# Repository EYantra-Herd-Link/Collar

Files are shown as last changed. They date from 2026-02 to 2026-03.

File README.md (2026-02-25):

# HerdLink Collar V1

HerdLink Collar V1 is a smart edge-computing tracking and health monitoring collar designed for livestock. Built around the Seeed Studio XIAO ESP32-C3, the collar integrates motion sensing, temperature and humidity monitoring, and audio analysis to infer animal behaviors such as grazing, ruminating, walking, and resting. It transmits telemetry data wirelessly via UDP.

## Features

*   **Behavioral Inference:** Utilizes a 6-axis IMU (MPU6050) to calculate activity jerk and variance, categorizing behavior into states like Grazing, Ruminating, Walking, Resting, and High/Low Activity Alerts.
*   **Audio Edge Processing:** Captures audio via an I2S microphone and performs on-device Fast Fourier Transform (FFT) to extract Mel-frequency features and audio magnitude.
*   **Health & Environmental Monitoring:** Measures body temperature using a Dallas DS18B20 sensor and environmental temperature/humidity using an AHT20 sensor.
*   **Power Efficiency:** Implements FreeRTOS tasks, hardware interrupts, and sleep modes (ESP32 Light Sleep) to optimize battery life.
*   **Wireless Telemetry:** Broadcasts structured JSON telemetry payloads over WiFi via UDP for local network collection.

## Hardware Components

*   **Microcontroller:** Seeed Studio XIAO ESP32-C3
*   **Motion Sensor:** MPU6050 (Accelerometer & Gyroscope)
*   **Body Temperature Sensor:** Dallas DS18B20 (OneWire)
*   **Environment Sensor:** AHT20 (Temperature & Humidity)
*   **Microphone:** I2S Microphone
*   **Custom PCB:** KiCad designs included for the main logic board and power management board.

## Project Structure

*   `Board Firmware/Sender/`: C++ PlatformIO project containing the ESP32-C3 edge firmware.
*   `Board Firmware/Reciever/`: Python script to receive and decode UDP telemetry data.
*   `PCB_Design/HerdLinkV1/`: KiCad project and Gerber files for the main collar PCB.
*   `PCB_Design/HerdLinkV1 Power/PowerBoard/`: KiCad project for the power management board.

## Setup and Installation

### 1. Firmware (Sender)

The firmware is built using PlatformIO.

1.  Open the `Board Firmware/Sender` directory in VS Code with the PlatformIO extension installed.
2.  Before flashing, update the WiFi credentials in `src/main.cpp`:
    ```cpp
    const char* WIFI_SSID     = "Your_SSID";
    const char* WIFI_PASSWORD = "Your_PASSWORD";
    ```
3.  Connect the XIAO ESP32-C3 and click the PlatformIO "Upload" button to compile and flash the firmware.

### 2. Receiver (Python script)

The receiver is a lightweight Python script that listens for incoming UDP packets.

1.  Navigate to the receiver directory:
    ```bash
    cd "Board Firmware/Reciever"
    ```
2.  Run the script (requires Python 3):
    ```bash
    python CowPilled.py
    ```
    The script will bind to `0.0.0.0:4210` and print incoming JSON telemetry payloads to the console.

## Telemetry Data Format

The device transmits data in JSON format over UDP. Example payload structure:

```json
{
  "id": "MAC_ADDRESS",
  "seq": 123,
  "ts": 1645000,
  "bt": 38.5,
  "et": 24.2,
  "eh": 45.0,
  "ax": 0.05,
  "ay": 0.98,
  "az": 0.12,
  "gx": 1.50,
  "gy": -0.20,
  "gz": 0.10,
  "gy_var": 0.054,
  "jerk": 45.2,
  "mot_int": 0,
  "err": 0,
  "v": 0.00,
  "s": -65,
  "af": [12.4, 45.2, 5.1, 0.0, 0.0, 0.0, 0.0, 0.0]
}
```

*   `id`: Device MAC address
*   `seq`: Sequence number
*   `ts`: Device uptime timestamp (ms)
*   `bt`: Body temperature (Celsius)
*   `et`: Environmental temperature (Celsius)
*   `eh`: Environmental humidity (%)
*   `ax`, `ay`, `az`: Accelerometer data
*   `gx`, `gy`, `gz`: Gyroscope data
*   `gy_var`: Gyroscope Y-axis variance
*   `jerk`: Calculated activity jerk
*   `mot_int`: Motion interrupt flag (1 if triggered, 0 otherwise)
*   `err`: Error code (currently 0)
*   `v`: Voltage (placeholder)
*   `s`: WiFi RSSI signal strength
*   `af`: Array of Audio Features (Mel bins)

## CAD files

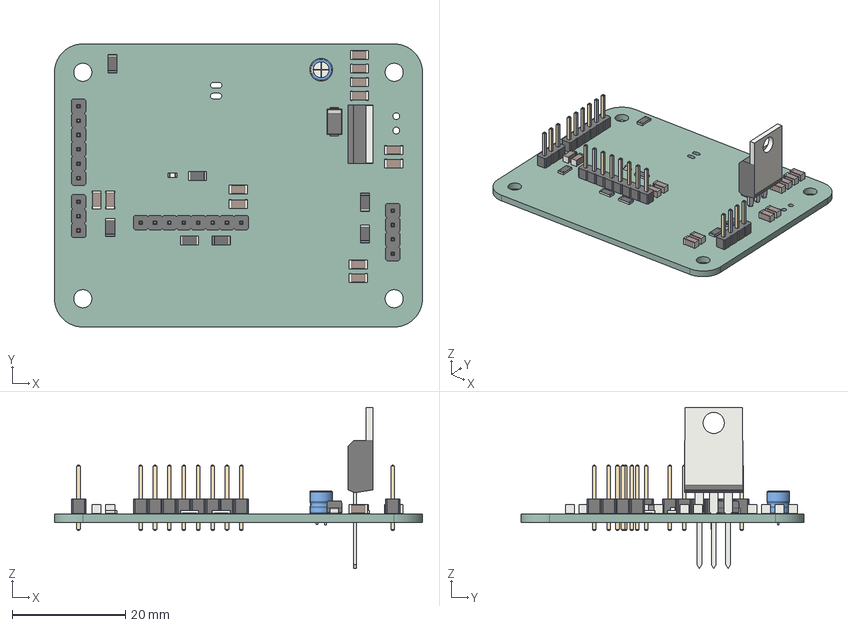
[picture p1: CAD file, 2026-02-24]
HerdLinkV1.step
65.0 x 50.0 x 28.5 mm
C_1206_3216Metric x 12
R_1206_3216Metric x 7
CP_Radial_D4.0mm_P1.50mm
D_SMA
PinHeader_1x03_P2.54mm_Vertical
PinHeader_1x04_P2.54mm_Vertical
PinHeader_1x08_P2.54mm_Vertical
PinHeader_1x06_P2.54mm_Vertical
LED_0603_1608Metric
TO-220-3_Vertical
HerdLinkV1_PCB

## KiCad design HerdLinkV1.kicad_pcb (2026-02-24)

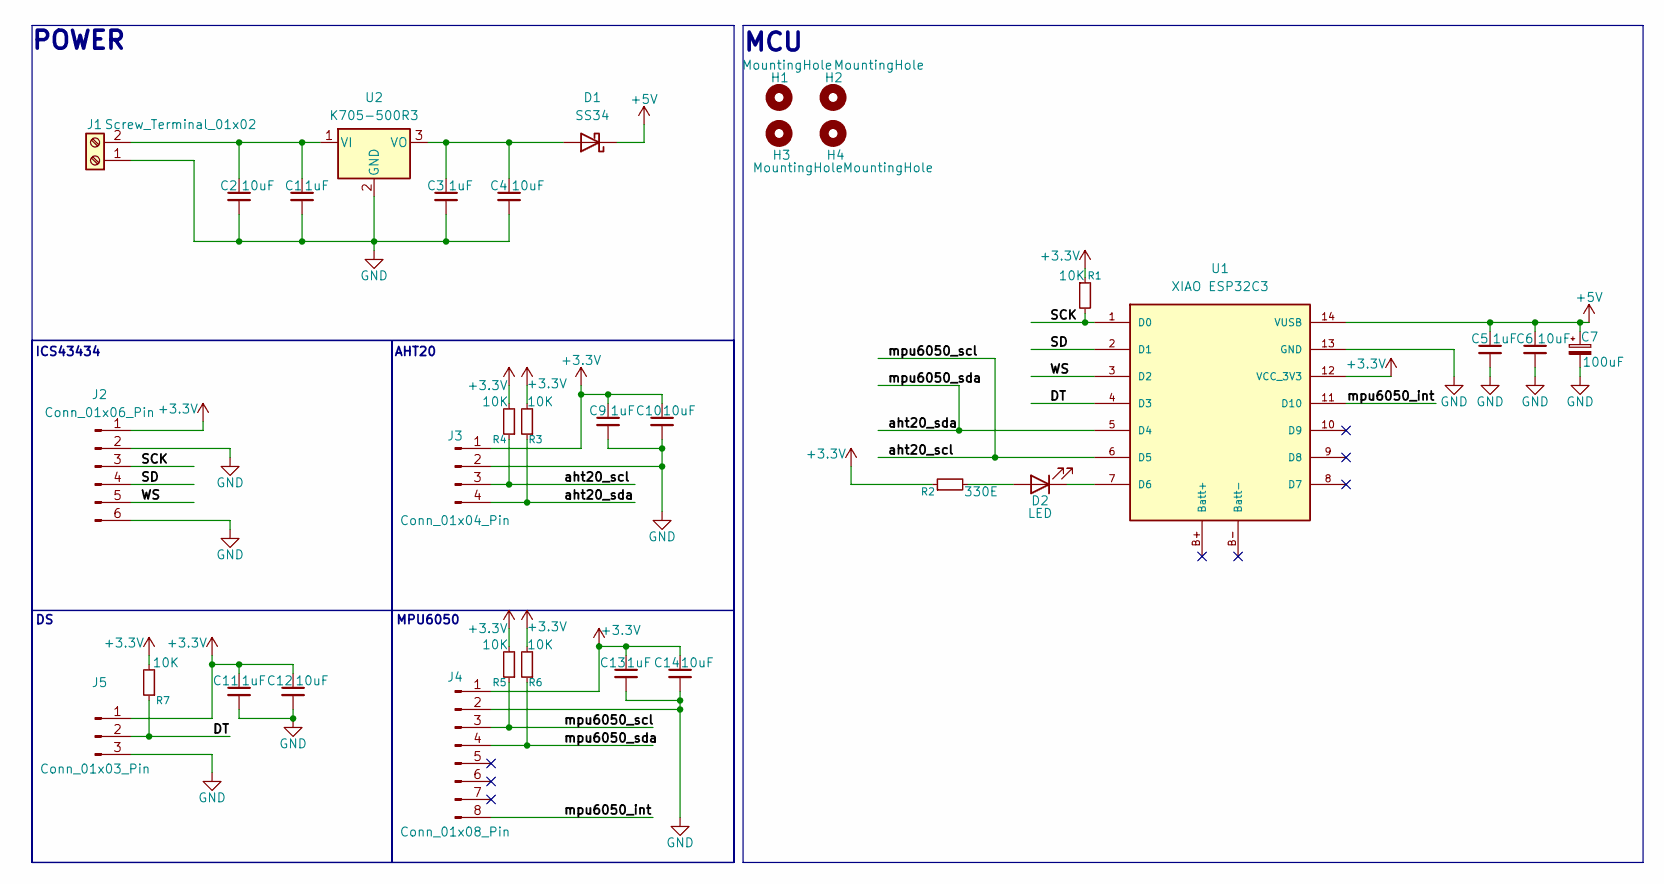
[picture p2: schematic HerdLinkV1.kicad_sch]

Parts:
C1, C3, C5, C9, C11, C13: 1uF; C_1206_3216Metric
C2, C4, C6, C10, C12, C14: 10uF; C_1206_3216Metric
C7: 100uF; CP_Radial_D4.0mm_P1.50mm
D1: SS34; D_SMA
D2: LED; LED_0603_1608Metric
H1, H2, H3, H4: MountingHole; MountingHole_3.2mm_M3
J1: Screw_Terminal_01x02; TerminalBlock_Xinya_XY308-2.54-2P_1x02_P2.54mm_Horizontal
J2: Conn_01x06_Pin; PinHeader_1x06_P2.54mm_Vertical
J3: Conn_01x04_Pin; PinHeader_1x04_P2.54mm_Vertical
J4: Conn_01x08_Pin; PinHeader_1x08_P2.54mm_Vertical
J5: Conn_01x03_Pin; PinHeader_1x03_P2.54mm_Vertical
R1, R3, R4, R5, R6, R7: 10K; R_1206_3216Metric_Pad1.30x1.75mm_HandSolder
R2: 330E; R_1206_3216Metric_Pad1.30x1.75mm_HandSolder
U1: XIAO ESP32C3; xiao_esp32c3
U2: K705-500R3; TO-220-3_Vertical

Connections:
+3.3V: C9.1, C10.1, C11.1, C12.1, C13.1, C14.1, J2.1, J3.1, J4.1, J5.1, R1.1, R2.1, R3.2, R4.2, R5.2, R6.2, R7.2, U1.12 (VCC_3V3)
+5V: C5.1, C6.1, C7.1, D1.1 (K), U1.14 (VUSB)
/DT: J5.2, R7.1, U1.4 (D3)
/SCK: J2.3, R1.2, U1.1 (D0)
/SD: J2.4, U1.2 (D1)
/WS: J2.5, U1.3 (D2)
/aht20_scl: J3.3, J4.3, R4.1, R5.1, U1.6 (D5)
/aht20_sda: J3.4, J4.4, R3.1, R6.1, U1.5 (D4)
/mpu6050_int: J4.8, U1.11 (D10)
GND: C1.2, C2.2, C3.2, C4.2, C5.2, C6.2, C7.2, C9.2, C10.2, C11.2, C12.2, C13.2, C14.2, J1.1, J2.2, J2.6, J3.2, J4.2, J5.3, U1.13 (GND), U2.2 (GND)
unnamed: C3.1, C4.1, D1.2 (A), U2.3 (VO)
unnamed: D2.2 (A), R2.2
unnamed: D2.1 (K), U1.7 (D6)
unnamed: C1.1, C2.1, J1.2, U2.1 (VI)

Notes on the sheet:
MCU
MPU6050
AHT20
ICS43434
POWER

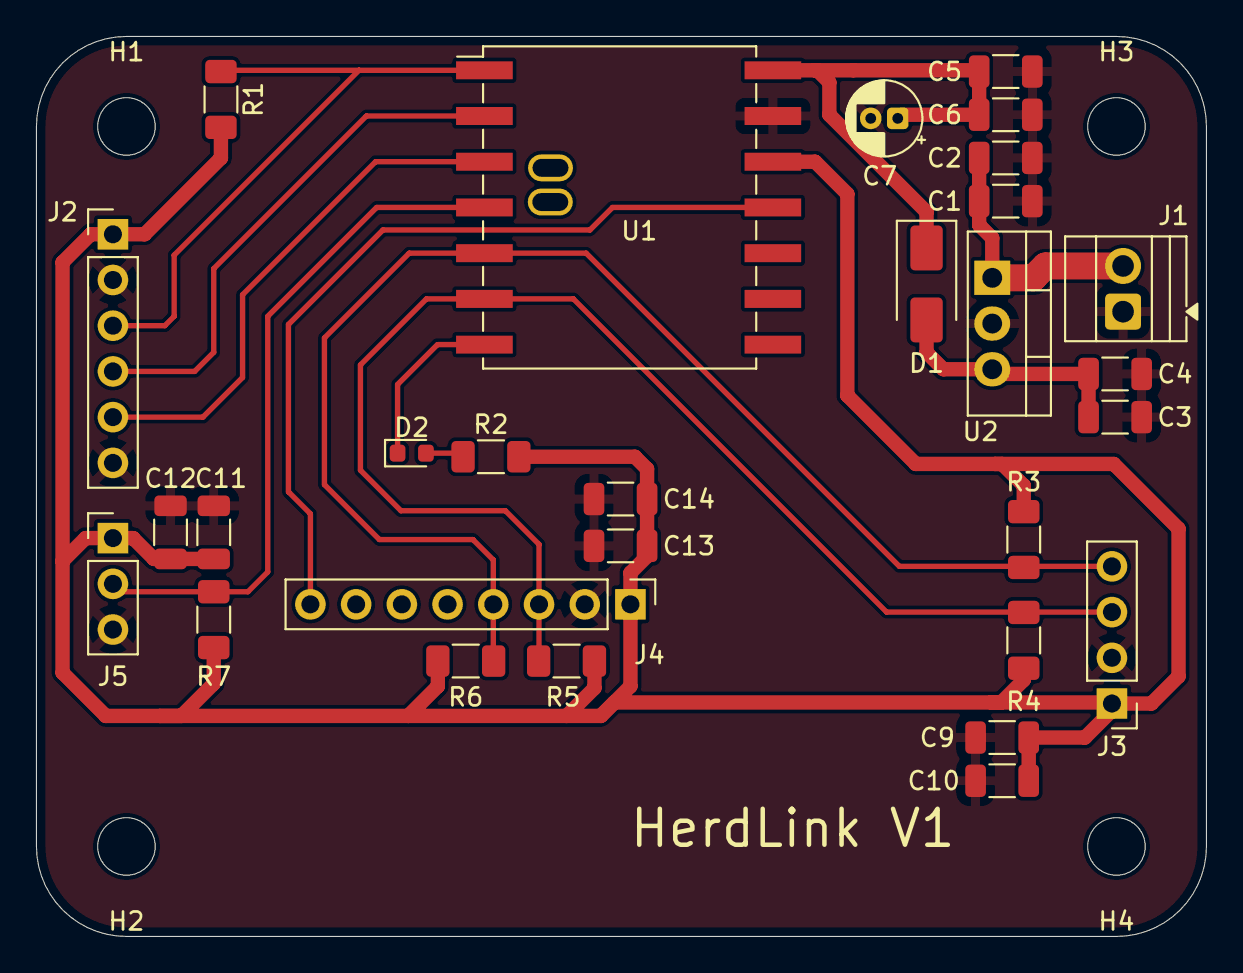
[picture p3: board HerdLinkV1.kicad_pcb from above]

Board: 2 copper layers, 65.0 x 50.0 mm, 33 parts (0 on the bottom side), 14 nets.

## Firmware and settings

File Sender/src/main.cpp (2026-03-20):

#include <Arduino.h>
#include <Wire.h>
#include <Adafruit_MPU6050.h>
#include <Adafruit_Sensor.h>
#include <esp_pm.h>
#include <esp_sleep.h>
#include <WiFi.h>
#include <WiFiUdp.h>
#include <esp_task_wdt.h>
#include <OneWire.h>
#include <DallasTemperature.h>
#include <Adafruit_AHTX0.h>
#include <driver/i2s.h>
#include <esp_mac.h>

#define PIN_I2C_SDA D4
#define PIN_I2C_SCL D5
#define PIN_LED     D6
#define PIN_MPU_INT D10
#define PIN_ONE_WIRE D3

#define I2S_SCK          D0
#define I2S_SD           D1
#define I2S_WS           D2
#define I2S_PORT         I2S_NUM_0
#define AUDIO_SAMPLE_RATE 16000
#define FFT_SIZE          256
#define NUM_MEL_BINS      8

#define IMU_SAMPLES_PER_CYCLE  10
#define IMU_SAMPLE_INTERVAL_MS 100

#define JERK_WALKING  5.0f
#define JERK_GRAZING  1.5f
#define JERK_MIN      0.3f

#define RUMINATION_AUDIO_THRESHOLD 50000.0f

const char* WIFI_SSID     = "placeholder";
const char* WIFI_PASSWORD = "placeholder";
const int   UDP_PORT      = 4210;
const char* TARGET_IP     = "255.255.255.255";

#define SENSOR_POLL_RATE_MS   10000
#define WDT_TIMEOUT_SECONDS   30
#define DS18B20_RESOLUTION    9

Adafruit_MPU6050  mpu;
Adafruit_AHTX0    aht20;
OneWire           oneWire(PIN_ONE_WIRE);
DallasTemperature ds18b20(&oneWire);

TaskHandle_t  TaskSensorHandle;
TaskHandle_t  TaskTelemetryHandle;
TaskHandle_t  TaskAudioHandle;
QueueHandle_t healthDataQueue;
SemaphoreHandle_t audioMutex;
WiFiUDP udp;

uint32_t seqNum    = 0;
bool ds18b20_ok    = false;
bool aht20_ok      = false;
bool mic_ok        = false;
char device_id[18];

float latestAudioMagnitude            = 0.0f;
float latestAudioFeatures[NUM_MEL_BINS] = {0};

int16_t cos_lut[FFT_SIZE / 2];
int16_t sin_lut[FFT_SIZE / 2];
int16_t window_lut[FFT_SIZE];

enum BehaviorState {
  RUMINATING,
  GRAZING,
  RESTING,
  WALKING,
  ALERT_HIGH_ACTIVITY,
  ALERT_LOW_ACTIVITY,
  UNKNOWN_STATE
};

struct HealthRecord {
  uint32_t      seq;
  uint32_t      timestamp;
  float         ax, ay, az;
  float         gx, gy, gz;
  float         gy_variance;
  float         activityJerk;
  bool          is_interrupt;
  float         bodyTemp;
  float         envTemp;
  float         envHum;
  BehaviorState state;
  float         audioMagnitude;
  float         audioFeatures[NUM_MEL_BINS];
};

void initDSP() {
  for (int i = 0; i < FFT_SIZE / 2; i++) {
    cos_lut[i] = (int16_t)(cos(2.0 * PI * i / FFT_SIZE) * 32767.0);
    sin_lut[i] = (int16_t)(sin(2.0 * PI * i / FFT_SIZE) * 32767.0);
  }
  for (int i = 0; i < FFT_SIZE; i++) {
    window_lut[i] = (int16_t)((0.54 - 0.46 * cos(2.0 * PI * i / (FFT_SIZE - 1))) * 32767.0);
  }
}

void int_fft(int16_t *fr, int16_t *fi, int n) {
  int m = 0;
  while ((1 << m) < n) m++;
  int j = 0;
  for (int i = 0; i < n - 1; i++) {
    if (i < j) {
      int16_t tr = fr[j]; int16_t ti = fi[j];
      fr[j] = fr[i]; fi[j] = fi[i];
      fr[i] = tr;    fi[i] = ti;
    }
    int k = n >> 1;
    while (k <= j) { j -= k; k >>= 1; }
    j += k;
  }
  for (int l = 1; l <= m; l++) {
    int le  = 1 << l;
    int le2 = le >> 1;
    for (j = 0; j < le2; j++) {
      int     idx = j << (m - l);
      int16_t wr  = cos_lut[idx];
      int16_t wi  = -sin_lut[idx];
      for (int i = j; i < n; i += le) {
        int     ip = i + le2;
        int32_t tr = ((int32_t)fr[ip] * wr - (int32_t)fi[ip] * wi) >> 15;
        int32_t ti = ((int32_t)fr[ip] * wi + (int32_t)fi[ip] * wr) >> 15;
        fr[ip] = fr[i] - tr;
        fi[ip] = fi[i] - ti;
        fr[i] += tr;
        fi[i] += ti;
      }
    }
  }
}

uint32_t int_sqrt(uint32_t n) {
  uint32_t root = 0;
  uint32_t bit  = 1UL << 30;
  while (bit > n) bit >>= 2;
  while (bit != 0) {
    if (n >= root + bit) {
      n   -= root + bit;
      root = (root >> 1) + bit;
    } else {
      root >>= 1;
    }
    bit >>= 2;
  }
  return root;
}

void IRAM_ATTR mpuInterruptHandler() {
  BaseType_t xHigherPriorityTaskWoken = pdFALSE;
  vTaskNotifyGiveFromISR(TaskSensorHandle, &xHigherPriorityTaskWoken);
  if (xHigherPriorityTaskWoken == pdTRUE) {
    portYIELD_FROM_ISR();
  }
}

void indicateBehavior(BehaviorState state) {
  switch (state) {
    case RUMINATING:
      digitalWrite(PIN_LED, LOW); vTaskDelay(pdMS_TO_TICKS(100));
      digitalWrite(PIN_LED, HIGH); vTaskDelay(pdMS_TO_TICKS(100));
      digitalWrite(PIN_LED, LOW); vTaskDelay(pdMS_TO_TICKS(100));
      digitalWrite(PIN_LED, HIGH);
      break;
    case GRAZING:
      digitalWrite(PIN_LED, LOW); vTaskDelay(pdMS_TO_TICKS(200));
      digitalWrite(PIN_LED, HIGH);
      break;
    case ALERT_HIGH_ACTIVITY:
    case ALERT_LOW_ACTIVITY:
      for (int i = 0; i < 5; i++) {
        digitalWrite(PIN_LED, LOW); vTaskDelay(pdMS_TO_TICKS(50));
        digitalWrite(PIN_LED, HIGH); vTaskDelay(pdMS_TO_TICKS(50));
      }
      break;
    default:
      digitalWrite(PIN_LED, LOW); vTaskDelay(pdMS_TO_TICKS(50));
      digitalWrite(PIN_LED, HIGH);
      break;
  }
}

void audioTask(void *pvParameters) {
  static int32_t raw_buffer[FFT_SIZE];  
  static int16_t fr[FFT_SIZE];
  static int16_t fi[FFT_SIZE];

  esp_task_wdt_add(NULL);

  for (;;) {
    esp_task_wdt_reset();

    if (ulTaskNotifyTake(pdTRUE, pdMS_TO_TICKS(5000)) == 0) {
      continue;
    }

    if (!mic_ok) continue;

    i2s_start(I2S_PORT);

    size_t bytes_read = 0;
    i2s_read(I2S_PORT, raw_buffer, sizeof(raw_buffer), &bytes_read, pdMS_TO_TICKS(100));

    uint64_t total_rms_sum               = 0;
    uint32_t mel_accumulators[NUM_MEL_BINS] = {0};
    int      frames_processed            = 0;
    bool     read_error                  = false;

    for (int i = 0; i < 187; i++) {
      if (i % 10 == 0) esp_task_wdt_reset();

      esp_err_t res = i2s_read(I2S_PORT, raw_buffer, sizeof(raw_buffer),
                               &bytes_read, pdMS_TO_TICKS(200));
      if (res != ESP_OK) {
        read_error = true;
        mic_ok     = false;
        break;
      }

      memset(fi, 0, sizeof(fi));

      for (int j = 0; j < FFT_SIZE; j++) {
        int32_t sample = raw_buffer[j] >> 12;
        fr[j] = (int16_t)((sample * window_lut[j]) >> 15);
        total_rms_sum += (uint64_t)(sample * sample);
      }

      int_fft(fr, fi, FFT_SIZE);

      int bin_width = (FFT_SIZE / 2) / NUM_MEL_BINS;
      for (int k = 0; k < FFT_SIZE / 2; k++) {
        uint32_t mag_sq  = ((uint32_t)(fr[k] * fr[k])) + ((uint32_t)(fi[k] * fi[k]));
        uint32_t mag     = int_sqrt(mag_sq);
        int      mel_idx = k / bin_width;
        if (mel_idx >= NUM_MEL_BINS) mel_idx = NUM_MEL_BINS - 1;
        mel_accumulators[mel_idx] += mag;
      }

      frames_processed++;
      vTaskDelay(pdMS_TO_TICKS(10));
    }

    i2s_stop(I2S_PORT);

    if (!read_error && frames_processed > 0) {
      uint32_t final_rms = int_sqrt(
        (uint32_t)(total_rms_sum / ((uint64_t)frames_processed * FFT_SIZE))
      );

      xSemaphoreTake(audioMutex, portMAX_DELAY);
      latestAudioMagnitude = (float)final_rms;
      for (int i = 0; i < NUM_MEL_BINS; i++) {
        latestAudioFeatures[i] = (float)mel_accumulators[i] / frames_processed;
      }
      xSemaphoreGive(audioMutex);
    }
  }
}

void sensorTask(void *pvParameters) {
  for (;;) {
    bool urgentMotion = false;

    if (ulTaskNotifyTake(pdTRUE, pdMS_TO_TICKS(SENSOR_POLL_RATE_MS)) > 0) {
      urgentMotion = true;
      Serial.println("WAKEUP: Interrupt Fired");
    } else {
      Serial.println("WAKEUP: Timer Poll");
    }

    digitalWrite(PIN_LED, LOW);

    float bTemp = 0.0f, eTemp = 0.0f, eHum = 0.0f;

    if (ds18b20_ok) {
      bTemp = ds18b20.getTempCByIndex(0);
      ds18b20.requestTemperatures();
      if (bTemp == DEVICE_DISCONNECTED_C || bTemp < -50.0f) {
        bTemp       = 0.0f;
        ds18b20_ok  = false;
      }
    } else {
      if (ds18b20.getDeviceCount() > 0) {
        ds18b20.setResolution(DS18B20_RESOLUTION);
        ds18b20.requestTemperatures();
        ds18b20_ok = true;
      }
    }

    if (aht20_ok) {
      sensors_event_t humidity, temp;
      if (aht20.getEvent(&humidity, &temp)) {
        eTemp = temp.temperature;
        eHum  = humidity.relative_humidity;
      } else {
        aht20_ok = false;
      }
    } else {
      if (aht20.begin()) {
        aht20_ok = true;
      }
    }

    mpu.enableCycle(false);
    mpu.enableSleep(false);
    vTaskDelay(pdMS_TO_TICKS(10));

    float sumAx = 0, sumAy = 0, sumAz = 0;
    float sumGx = 0, sumGy = 0, sumGz = 0;
    float gyroYSamples[IMU_SAMPLES_PER_CYCLE];
    float totalJerk  = 0.0f;
    float prevMag    = 0.0f;
    int   validSamples = 0;

    for (int i = 0; i < IMU_SAMPLES_PER_CYCLE; i++) {
      sensors_event_t a, g, temp;
      if (mpu.getEvent(&a, &g, &temp)) {
        sumAx += a.acceleration.x;
        sumAy += a.acceleration.y;
        sumAz += a.acceleration.z;
        sumGx += g.gyro.x;
        sumGy += g.gyro.y;
        sumGz += g.gyro.z;
        gyroYSamples[validSamples] = g.gyro.y;

        float mag = sqrt(a.acceleration.x * a.acceleration.x +
                         a.acceleration.y * a.acceleration.y +
                         a.acceleration.z * a.acceleration.z);
        if (i > 0) totalJerk += abs(mag - prevMag);
        prevMag = mag;
        validSamples++;
      }
      vTaskDelay(pdMS_TO_TICKS(IMU_SAMPLE_INTERVAL_MS));
    }

    HealthRecord rec = {0};
    rec.seq          = seqNum++;
    rec.timestamp    = millis();
    rec.is_interrupt = urgentMotion;
    rec.bodyTemp     = bTemp;
    rec.envTemp      = eTemp;
    rec.envHum       = eHum;

    if (validSamples > 0) {
      rec.ax = sumAx / validSamples;
      rec.ay = sumAy / validSamples;
      rec.az = sumAz / validSamples;
      rec.gx = sumGx / validSamples;
      rec.gy = sumGy / validSamples;
      rec.gz = sumGz / validSamples;

      float mean     = rec.gy;
      float variance = 0.0f;
      for (int i = 0; i < validSamples; i++) {
        float diff = gyroYSamples[i] - mean;
        variance += diff * diff;
      }
      rec.gy_variance = variance / validSamples;
    }

    rec.activityJerk = (validSamples > 1) ? totalJerk / (validSamples - 1) : 0.0f;

    if (urgentMotion) {
      rec.state = ALERT_HIGH_ACTIVITY;
      if (mic_ok) {
        xTaskNotifyGive(TaskAudioHandle);
      }
    } else if (rec.activityJerk > JERK_WALKING * 2.0f) {
      rec.state = ALERT_HIGH_ACTIVITY;
    } else if (rec.activityJerk > JERK_WALKING) {
      rec.state = WALKING;
    } else if (rec.activityJerk > JERK_GRAZING) {
      rec.state = GRAZING;
    } else {
      rec.state = RESTING;
    }

    indicateBehavior(rec.state);

    xSemaphoreTake(audioMutex, portMAX_DELAY);
    rec.audioMagnitude = latestAudioMagnitude;
    for (int i = 0; i < NUM_MEL_BINS; i++) {
      rec.audioFeatures[i] = latestAudioFeatures[i];
    }
    latestAudioMagnitude = 0.0f;
    memset(latestAudioFeatures, 0, sizeof(latestAudioFeatures));
    xSemaphoreGive(audioMutex);

    if (rec.state == RESTING && rec.audioMagnitude > RUMINATION_AUDIO_THRESHOLD) {
      rec.state = RUMINATING;
    }

    xQueueSend(healthDataQueue, &rec, pdMS_TO_TICKS(100));

    mpu.setInterruptPinLatch(false);
    mpu.setCycleRate(MPU6050_CYCLE_40_HZ);
    mpu.enableCycle(true);

    vTaskDelay(pdMS_TO_TICKS(100));
    digitalWrite(PIN_LED, HIGH);

    if (urgentMotion) {
      mpu.getMotionInterruptStatus();
    }
  }
}

void telemetryTask(void *pvParameters) {
  esp_task_wdt_add(NULL);

  for (;;) {
    esp_task_wdt_reset();

    HealthRecord rec;
    if (xQueueReceive(healthDataQueue, &rec, pdMS_TO_TICKS(5000)) == pdPASS) {

      if (WiFi.status() != WL_CONNECTED) {
        Serial.println("WiFi: Connecting...");
        WiFi.begin(WIFI_SSID, WIFI_PASSWORD);
        int retries = 0;
        while (WiFi.status() != WL_CONNECTED && retries < 10) {
          esp_task_wdt_reset();
          vTaskDelay(pdMS_TO_TICKS(500));
          retries++;
        }
        if (WiFi.status() == WL_CONNECTED) {
          Serial.println("WiFi: Connected!");
        } else {
          Serial.println("WiFi: Failed to connect.");
        }
      }

      if (WiFi.status() == WL_CONNECTED) {
        char af_buf[128] = "[";
        for (int i = 0; i < NUM_MEL_BINS; i++) {
          char temp[16];
          snprintf(temp, sizeof(temp), "%.2f%s",
                   rec.audioFeatures[i],
                   (i == NUM_MEL_BINS - 1) ? "" : ",");
          strlcat(af_buf, temp, sizeof(af_buf));
        }
        strlcat(af_buf, "]", sizeof(af_buf));

        char payload[896];
        snprintf(payload, sizeof(payload),
          "{"
          "\"id\":\"%s\","
          "\"seq\":%u,"
          "\"ts\":%u,"
          "\"bt\":%.1f,"
          "\"et\":%.1f,"
          "\"eh\":%.1f,"
          "\"ax\":%.2f,\"ay\":%.2f,\"az\":%.2f,"
          "\"gx\":%.2f,\"gy\":%.2f,\"gz\":%.2f,"
          "\"gy_var\":%.3f,"
          "\"jerk\":%.2f,"
          "\"aud\":%.2f,"
          "\"state\":%d,"
          "\"mot_int\":%d,"
          "\"low_act\":%d,"
          "\"err\":0,"
          "\"v\":0.00,"
          "\"s\":%d,"
          "\"af\":%s"
          "}",
          device_id, rec.seq, rec.timestamp,
          rec.bodyTemp, rec.envTemp, rec.envHum,
          rec.ax, rec.ay, rec.az,
          rec.gx, rec.gy, rec.gz,
          rec.gy_variance, rec.activityJerk, rec.audioMagnitude,
          (int)rec.state,
          rec.is_interrupt ? 1 : 0,
          (rec.activityJerk < JERK_MIN && rec.activityJerk >= 0.0f) ? 1 : 0,
          (int)WiFi.RSSI(),
          af_buf
        );

        Serial.println(payload);

        udp.beginPacket(TARGET_IP, UDP_PORT);
        udp.print(payload);
        udp.endPacket();

        Serial.println("UDP: Sent.");
      }

      if (uxQueueMessagesWaiting(healthDataQueue) == 0) {
        WiFi.disconnect(true);
        WiFi.mode(WIFI_OFF);
      }
    }
  }
}

void setup() {
  Serial.begin(115200);
  pinMode(PIN_LED, OUTPUT);
  digitalWrite(PIN_LED, HIGH);

  Wire.begin(PIN_I2C_SDA, PIN_I2C_SCL);
  Wire.setClock(100000);
  Wire.setTimeOut(50);

  esp_pm_config_esp32c3_t pm_config = {
    .max_freq_mhz       = 160,
    .min_freq_mhz       = 10,
    .light_sleep_enable = true
  };
  esp_pm_configure(&pm_config);

  esp_task_wdt_init(WDT_TIMEOUT_SECONDS, true);

  WiFi.mode(WIFI_STA);
  uint8_t mac[6];
  esp_read_mac(mac, ESP_MAC_WIFI_STA);
  snprintf(device_id, sizeof(device_id), "%02X:%02X:%02X:%02X:%02X:%02X",
           mac[0], mac[1], mac[2], mac[3], mac[4], mac[5]);

  initDSP();

  ds18b20.begin();
  if (ds18b20.getDeviceCount() > 0) {
    ds18b20.setResolution(DS18B20_RESOLUTION);
    ds18b20.requestTemperatures();
    ds18b20_ok = true;
  }

  if (aht20.begin()) {
    aht20_ok = true;
  }

  if (!mpu.begin()) {
    while (1) delay(10);
  }

  mpu.setAccelerometerRange(MPU6050_RANGE_8_G);
  mpu.setGyroRange(MPU6050_RANGE_500_DEG);        
  mpu.setFilterBandwidth(MPU6050_BAND_21_HZ);     

  mpu.setMotionDetectionThreshold(10);             
  mpu.setMotionDetectionDuration(1);
  mpu.setInterruptPinLatch(false);
  mpu.setInterruptPinPolarity(true);
  mpu.setMotionInterrupt(true);

  mpu.enableSleep(false);
  mpu.setCycleRate(MPU6050_CYCLE_40_HZ);
  mpu.enableCycle(true);

  pinMode(PIN_MPU_INT, INPUT_PULLDOWN);

  i2s_config_t i2s_config = {
    .mode                 = (i2s_mode_t)(I2S_MODE_MASTER | I2S_MODE_RX),
    .sample_rate          = AUDIO_SAMPLE_RATE,
    .bits_per_sample      = I2S_BITS_PER_SAMPLE_32BIT,
    .channel_format       = I2S_CHANNEL_FMT_ONLY_LEFT,
    .communication_format = I2S_COMM_FORMAT_STAND_I2S,
    .intr_alloc_flags     = ESP_INTR_FLAG_LEVEL1,
    .dma_buf_count        = 4,
    .dma_buf_len          = 512,
    .use_apll             = false,
    .tx_desc_auto_clear   = false,
    .fixed_mclk           = 0
  };
  i2s_pin_config_t pin_config = {
    .bck_io_num   = I2S_SCK,
    .ws_io_num    = I2S_WS,
    .data_out_num = I2S_PIN_NO_CHANGE,
    .data_in_num  = I2S_SD
  };

  if (i2s_driver_install(I2S_PORT, &i2s_config, 0, NULL) == ESP_OK) {
    i2s_set_pin(I2S_PORT, &pin_config);
    i2s_stop(I2S_PORT);
    mic_ok = true;
  }

  healthDataQueue = xQueueCreate(20, sizeof(HealthRecord));
  audioMutex      = xSemaphoreCreateMutex();

  xTaskCreate(sensorTask,    "SensorTask",    4096, NULL, 3, &TaskSensorHandle);
  xTaskCreate(telemetryTask, "TelemetryTask", 8192, NULL, 2, &TaskTelemetryHandle);
  xTaskCreate(audioTask,     "AudioTask",     8192, NULL, 1, &TaskAudioHandle);

  mpu.getMotionInterruptStatus();

  gpio_wakeup_enable((gpio_num_t)PIN_MPU_INT, GPIO_INTR_HIGH_LEVEL);
  esp_sleep_enable_gpio_wakeup();

  attachInterrupt(digitalPinToInterrupt(PIN_MPU_INT), mpuInterruptHandler, RISING);
}

void loop() {
  vTaskDelete(NULL);
}

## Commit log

2026-02-22 Minor bug fixes with the watchdog timer.
2026-02-24 Added PCB files
    [HerdLinkV1.kicad_pcb, HerdLinkV1.kicad_sch, HerdLinkV1.step]
2026-02-25 Updated firmware with working motion interrupts and RSSI updates
